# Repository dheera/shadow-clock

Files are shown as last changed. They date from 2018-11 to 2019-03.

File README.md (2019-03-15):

# shadow-clock

A simple 3D-printable wall clock that displays time using shadows.

This was inspired by a number of similar projects [0](https://www.coroflot.com/ukeskin/Shadow-Clock) [1](https://atmelcorporation.wordpress.com/2015/10/23/shadowplay-is-like-an-arduino-powered-sundial-for-a-wall/) [2](https://solarbotics.com/product/60400/) but I wanted to create something that was simpler, cheaper, and easier to assemble now that we have these amazing individually-addressable LED strips that take only 3 wires to connect.

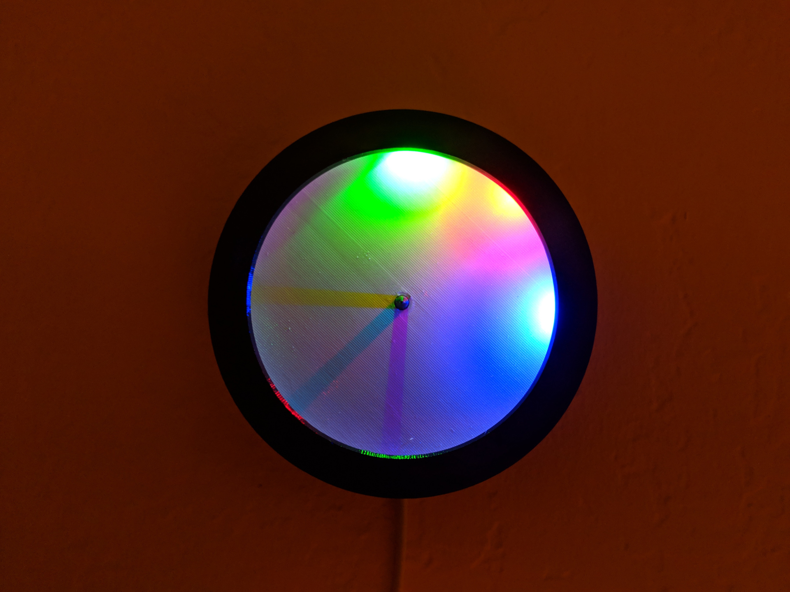
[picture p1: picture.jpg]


## 3D printing

4 parts in /design/:
* clock-small-back, clock-small-front, clock-small-cover -- print in black or any color
* clock-small-face -- print in white

## COTS parts

* 144 pixel/m WS2812B strip [Source 0](https://www.amazon.com/gp/product/B01CDTEGGO/) [Source 1](https://www.adafruit.com/product/1506)
* WeMos D1 Mini V2 [Source 0](https://www.amazon.com/gp/product/B01MYSYYKX/)
* Right angle header [Source 0](https://www.amazon.com/Simpo-2-54mm-Connector-Plastic-Gold-plated/dp/B07DRDZ18M/)
* USB A to USB micro-B cable [Source 0](https://www.amazon.com/gp/product/B012WHAG7K/)
* Glue [SCIGRIP 16 for PETG](https://www.amazon.com/gp/product/B003HNFLMY/)

## Assembly

Soldering to the flexible strip's contacts can be tricky but assembly is otherwise pretty straightforward. The one thing to make sure of is that you properly cut off the contacts on the last LED so that it doesn't send signals going back around the clock indefinitely.

You'll need to use glue to fix clock-small-back to clock-small-front. If you're printing with PETGThe Wemos D1 Mini V2 should snap into the bracket on the back. Once you have the strip mounted you can then use some lighter adhesive to affix clock-small-face in case you need to remove it later.

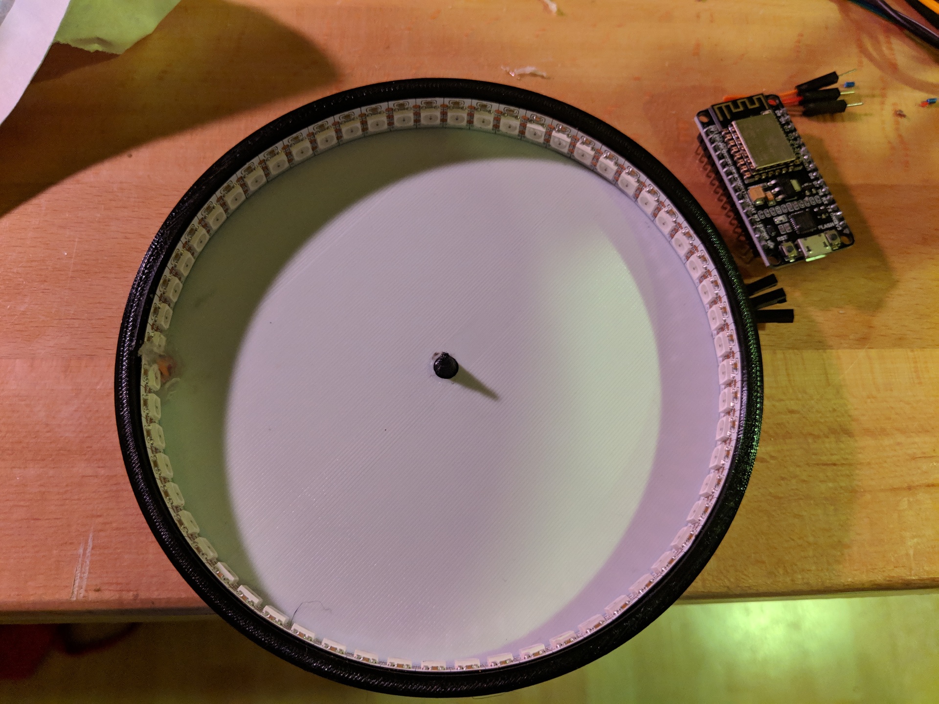
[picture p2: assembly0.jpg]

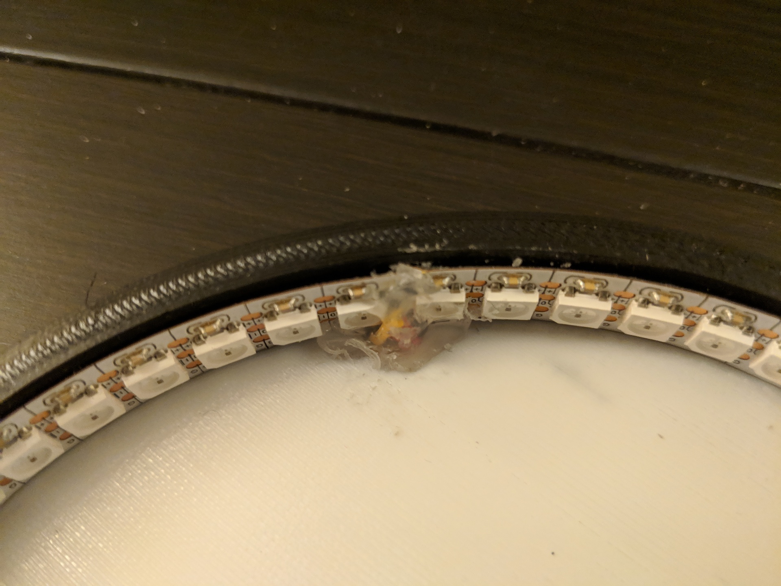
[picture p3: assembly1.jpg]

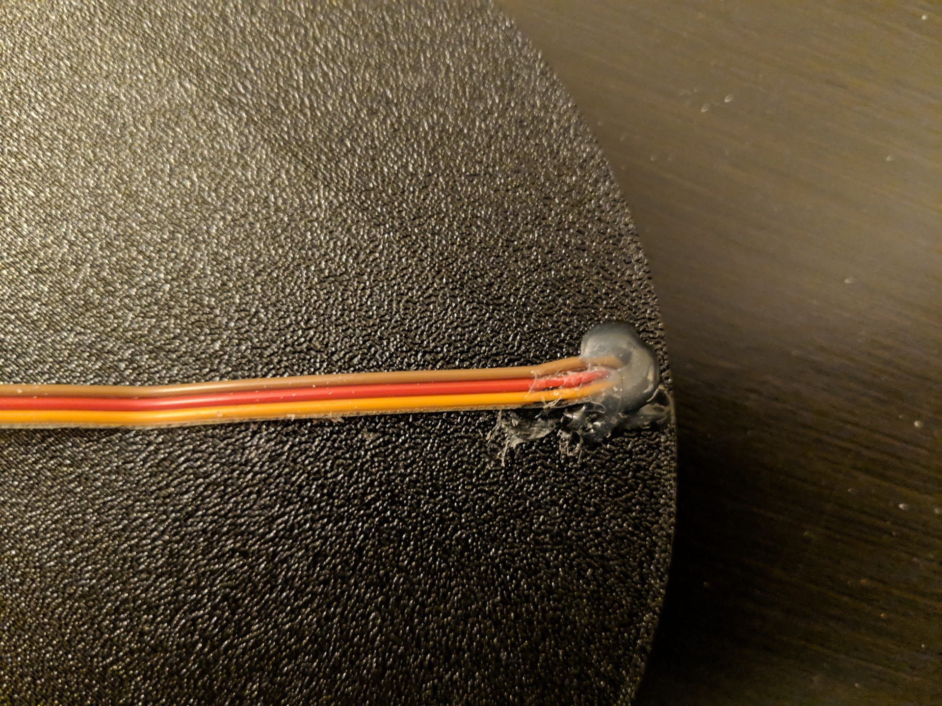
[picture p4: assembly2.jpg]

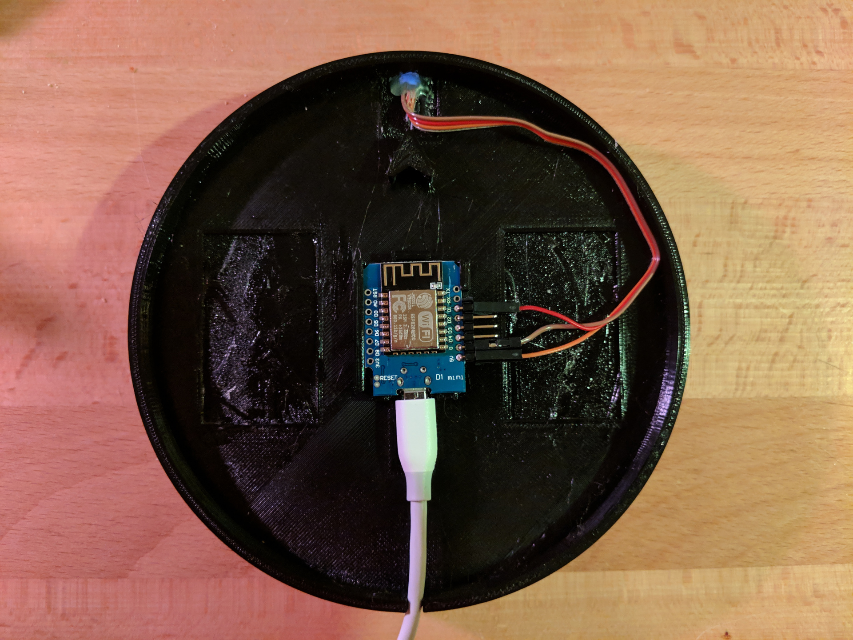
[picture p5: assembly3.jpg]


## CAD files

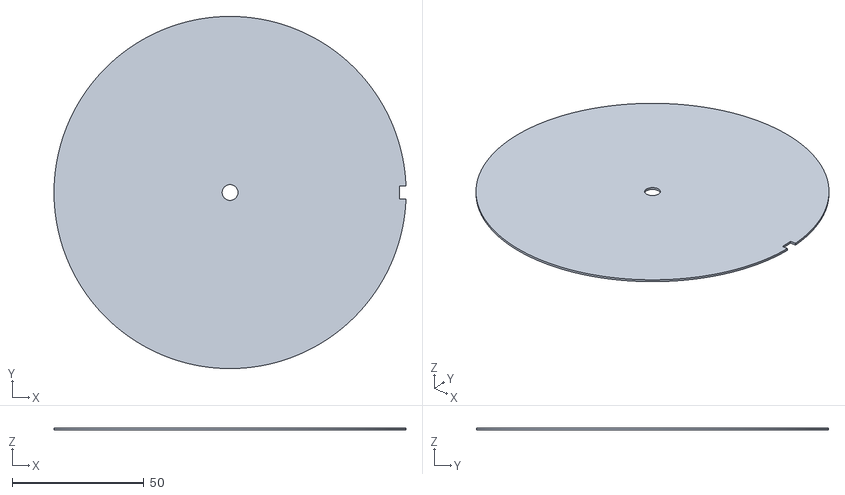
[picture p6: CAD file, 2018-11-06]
design/clock-small-face.stl
133.8 x 133.8 x 0.8

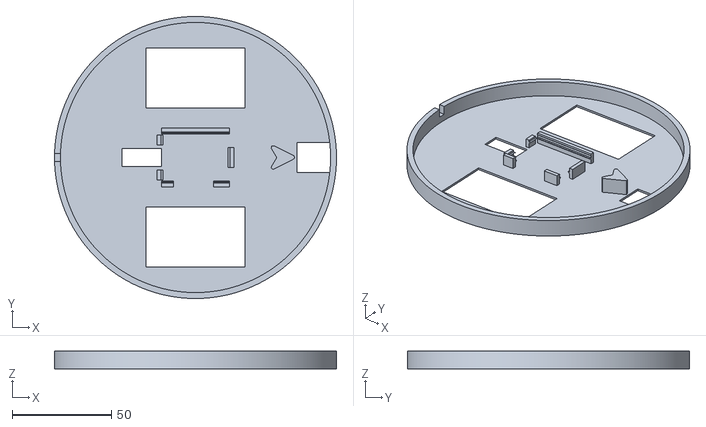
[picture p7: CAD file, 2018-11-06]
design/clock-small-back.stl
141.9 x 141.9 x 9.00

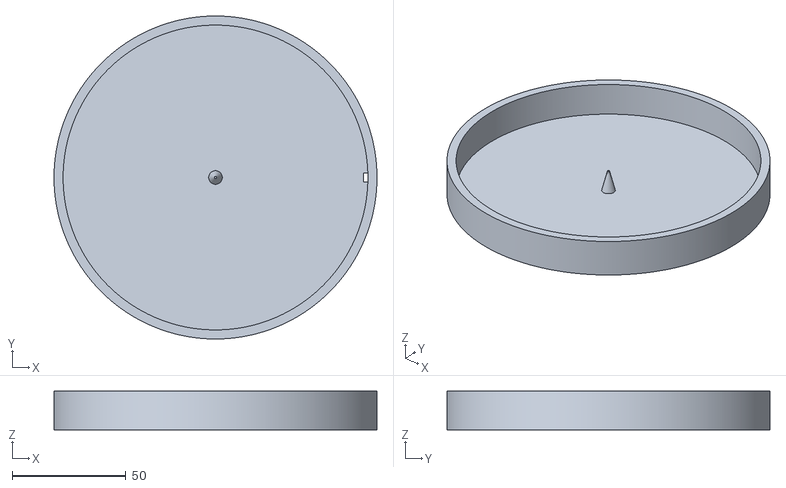
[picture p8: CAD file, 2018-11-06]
design/clock-small-front.stl
141.9 x 141.9 x 17.0

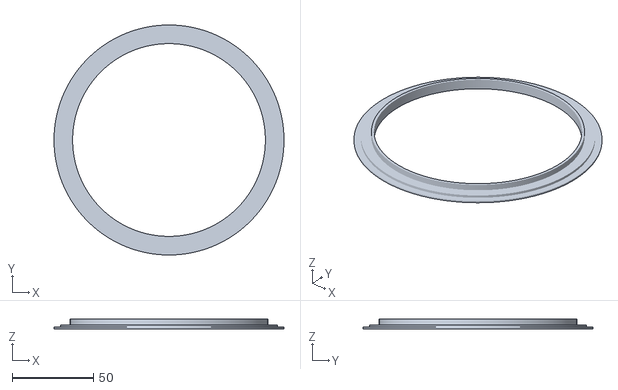
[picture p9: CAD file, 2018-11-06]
design/clock-small-cover.stl
141.9 x 141.9 x 6.00

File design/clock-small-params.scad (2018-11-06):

fn = 512;

leds_per_m = 144;
strip_width = 12;
fudge_factor = 4;

d_inner = 60/leds_per_m/3.141592653*1000 + fudge_factor/3.141592653589;
d_outer = d_inner+8;
h_inner = strip_width;

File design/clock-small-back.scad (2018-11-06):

include<clock-small-params.scad>

// panel with cutouts
difference() {
    cylinder(h=1,d=d_outer,$fn=fn);
    translate([d_outer/2,0,0])
    cube([40,15,2],center=true);
    translate([-27,0,0])
    cube([20,9,2],center=true);
    
    translate([0,40,0])
    cube([50,30,2],center=true);
    translate([0,-40,0])
    cube([50,30,2],center=true);
    
}

// outer wall
difference() {
    cylinder(h=9,d=d_outer,$fn=fn);
    cylinder(h=12,d=d_outer-6,$fn=fn);
    translate([d_outer/2-3.75,0,0])
    cube([5,5,8],center=true);
    
    translate([-d_outer/2,0,8])
    cube([10,4,7],center=true);
}

// mount for wemos D1 R2
translate([0,0,1])
wemos();

// mount for nail hanger
translate([47,0,0])
hanger();

module hanger() {
    rotate([0,0,-90]) {
    linear_extrude(8)
    minkowski() {
        polygon([[0,2],[-5,-8],[0,1],[5,-8]]);
        circle(r=1);
    }
    translate([0,0,8])
    linear_extrude(1)
    minkowski() {
        polygon([[0,2],[-5,-8],[0,-5],[5,-8]]);
        circle(r=1);
    }
}
}


module wemos() {

translate([0,25.8/2,0]) {
bracket(length=34);

translate([13,-25.8,0])
rotate([0,0,180])
bracket(length=8);

translate([-14,-25.8,0])
rotate([0,0,180])
bracket(length=6);
    
translate([17.3,-25.8/2,0])
rotate([0,0,-90])
wall(length=10,boardThickness=2.2);

translate([-17.3,-4,0])
rotate([0,0,90])
wall(length=5);

translate([-17.3,-25.8+4,0])
rotate([0,0,90])
wall(length=5);
    
}
}

module wall(height=3.5, thickness=2,length=10, boardThickness=1) {
translate([-length/2,0,0])
cube([length,thickness,height+boardThickness]);

translate([0,0,height])
difference() {
    translate([0,0,-1])
    rotate([45,0,0])
    translate([-length/2,0,0])
    cube([length,sqrt(2),sqrt(2)]);
    
    translate([-length/2,-1,0])
    cube([length,2,2]);
}

}

module bracket(height=3.5, thickness=2,length=10, boardThickness=1.2) {
translate([-length/2,0,0])
cube([length,thickness,height+1+boardThickness]);


translate([0,0,height])
difference() {
    translate([0,0,-1])
    rotate([45,0,0])
    translate([-length/2,0,0])
    cube([length,sqrt(2),sqrt(2)]);
    
    translate([-length/2,-1,0])
    cube([length,2,2]);
}

translate([0,0,height+1+boardThickness])
    translate([0,0,-1])
    rotate([45,0,0])
    translate([-length/2,0,0])
    cube([length,sqrt(2)/2,sqrt(2)/2]);

}

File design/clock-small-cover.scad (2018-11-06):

include<clock-small-params.scad>

difference() {
    cylinder(d=d_outer,h=1,$fn=fn);
    cylinder(d=d_inner-15,h=1,$fn=fn);
}

difference() {
    cylinder(d=d_inner,h=2.5,$fn=fn);
    cylinder(d=d_inner-15,h=2.5,$fn=fn);
}

difference() {
    cylinder(d=d_inner-12,h=6,$fn=fn);
    cylinder(d=d_inner-15,h=6,$fn=fn);
}

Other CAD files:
design/clock-small-face.scad
design/clock-small-front.scad

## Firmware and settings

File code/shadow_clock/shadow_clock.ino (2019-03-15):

#include <Adafruit_NeoPixel.h>
#include <ESP8266WiFi.h>
#include <time.h>

#define PIN 5     // the data pin from the Wemos D1 Mini used for the NeoPixel strip
#define N_LEDS 60 // don't change this

const char* ssid     = "YOURSSIDHERE";
const char* password = "YOURPASSWORDHERE";
const char* host     = "time.nist.gov";

// UTC timezone -- change it to yours if you wish
const int timezone_offset_secs = 0;
const int dst_offset_secs = 0;

Adafruit_NeoPixel strip = Adafruit_NeoPixel(N_LEDS, PIN, NEO_GRB + NEO_KHZ800);

void setup() {
  Serial.begin(115200);
  delay(1000);
  
  Serial.println("initializing strip");
  strip.begin();
  delay(1000);

  Serial.println("initializing wifi");
  WiFi.mode(WIFI_STA);
  WiFi.disconnect();
  WiFi.begin(ssid, password);

  while (WiFi.status() != WL_CONNECTED) {
    Serial.print(".");
    delay(100);
  }

  syncTime();
}

int h = 6;
int m = 24;
int s = 55;
int brightness = 255;
int count = 0;

void loop() {

  // re-sync to the atomic clock every 1 hour
  count = (count + 1) % 3600;
  if(count == 0) {
    syncTime();
  }

  time_t now = time(nullptr);  
  Serial.println(ctime(&now));

  struct tm* timeinfo;
  timeinfo = localtime(&now);

  h = timeinfo->tm_hour;
  m = timeinfo->tm_min;
  s = timeinfo->tm_sec;

  brightness = 255;
  
  setTimePixels((h%12)*5 + (m*5/60), m ,s, brightness);

  delay(1000);
}

static void setTimePixels(int r, int g, int b, int brightness) {
  int oppR = 59 - ((r+30)%60);
  int oppG = 59 - ((g+30)%60);
  int oppB = 59 - ((b+30)%60);
  
  uint32_t black = strip.Color(0,0,0);
  uint32_t red = strip.Color(brightness,0,0);
  uint32_t green = strip.Color(0,brightness,0);
  uint32_t blue = strip.Color(0,0,brightness);

  int pixelColor;
  for(uint16_t i=0;i<60;i++) {
    pixelColor = black;
    if(i==oppR) {
      pixelColor += red;
    }
    if(i==oppG) {
      pixelColor += green;
    }
    if(i==oppB) {
      pixelColor += blue;
    }
    strip.setPixelColor(i, pixelColor);
  }
  strip.show();
}

static void syncTime() {
  configTime(timezone_offset_secs, dst_offset_secs, "pool.ntp.org", "time.nist.gov");
  
  Serial.println("\nWaiting for time");
  while (!time(nullptr)) {
    Serial.print(".");
    delay(100);
  }
  Serial.println("");
}
